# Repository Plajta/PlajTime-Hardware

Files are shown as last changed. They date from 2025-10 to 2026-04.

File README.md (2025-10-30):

# PlajTime Hardware
This repository has the full history of PlajTime hardware development.
Before 19.9.2025 development took place in a single private repository and it was starting to be a little bit messy.
With beginning work on PlajTime's second prototype we made the decision to split the repos and make the code and design finally available.

## What about the older versions?
Every "release" will have it's own tag so you (and we) can look at the older versions and laugh how bad at engineering we are.

## License

This project is licensed under the [Creative Commons Attribution-NonCommercial-ShareAlike 4.0 International License](https://creativecommons.org/licenses/by-nc-sa/4.0/).



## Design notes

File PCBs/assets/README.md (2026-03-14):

# PlajTime PCB Assets
- `source files` - contains sources for further editing - state before converting broken things and fonts to paths
- For some text we used the awesome ISO style font [osifont](https://github.com/hikikomori82/osifont)

## How to align full board SVG graphics
- open the import graphics menu
- disable "Fix discontinuities"
- set scale to 1.0
- `lime.svg`
    - Align RP USB GND pin and Main flash corners with the alignment marks in the SVG
- `aux_*.svg`
    - Align the GND pogo pad on USB and GND pad on slider controller
- `bat_*.svg`
    - Align the two vias to GND and BATT_NTC
- Double click any part of the SVG and click on the alignment marks to delete them
- Profit

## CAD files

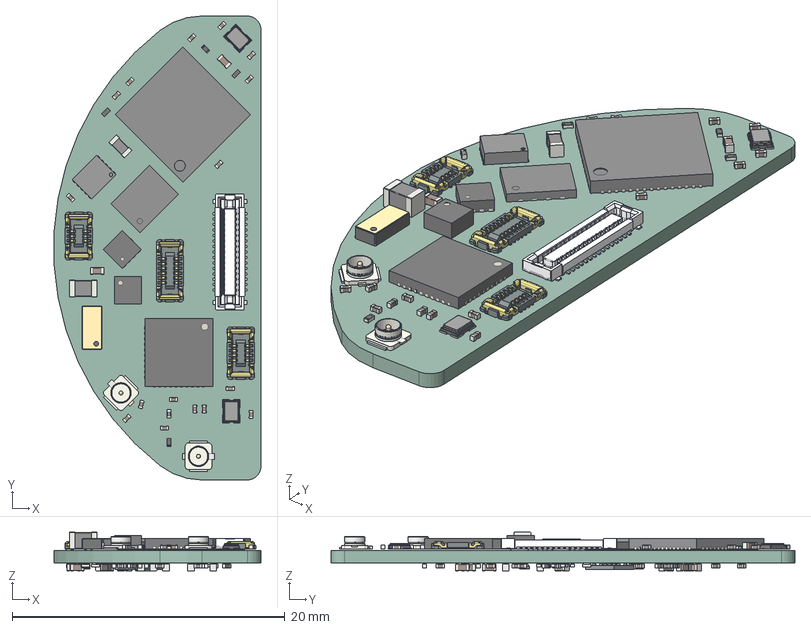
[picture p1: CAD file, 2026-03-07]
PCBs/plajtime-main/plajtime-main.step
15.2 x 34.0 x 2.83 mm
C_0201_0603Metric x 33
R_0201_0603Metric x 12
LGA-12_2x2mm_P0.5mm
L_0603_1608Metric
Texas_RUN0010A_WQFN-10_2x2mm_P0.5mm
Crystal_SMD_WE_IQXC-26-4Pin_1.6x1.2mm x 2
QFN-40-1EP_5x5mm_P0.4mm_EP3.6x3.6mm
U.FL_Hirose_U.FL-R-SMT-1_Vertical x 2
Rect2
Rect3
Rect4
Rect5
Terminal
ThermalPin
PinsArrayLR
W25Q64JWUUIQ_TR
L_0201_0603Metric x 2
L_0805_2012Metric
axe530127
C_0402_1005Metric x 12
RP2350A-QFN60
L_0402_1005Metric
Texas_DSBGA-6_0.757x1.01mm_Layout2x3_P0.35mm
R_0402_1005Metric
W25Q64JWBYIM_TR
plajtime-main_PCB

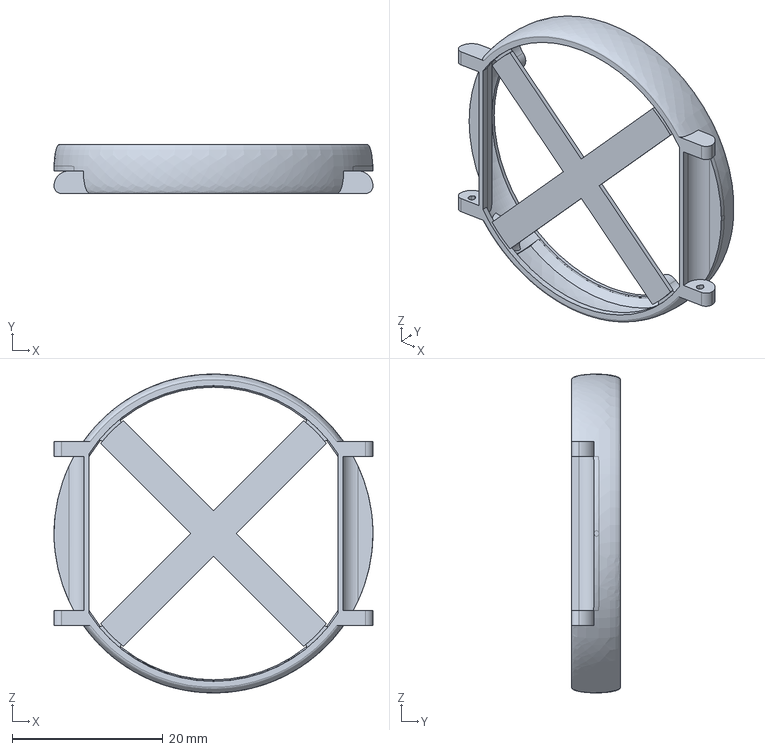
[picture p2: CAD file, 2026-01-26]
3D/STLs/PlajTime-mainFrame.step
42.3 x 6.50 x 42.3 mm

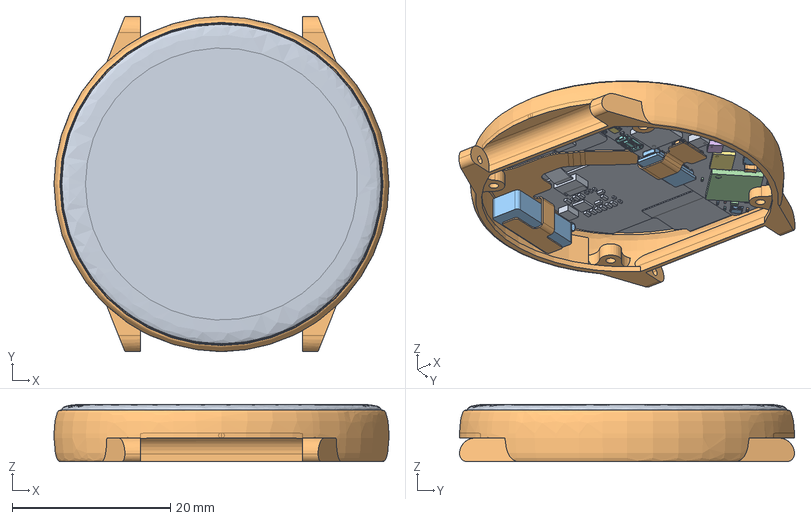
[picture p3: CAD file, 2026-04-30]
3D/PlajTime.FCStd
42.3 x 42.3 x 7.25 mm
display
mainFrame
haptic
C_0201_0603Metric
C_0201_0603Metric001
R_0201_0603Metric
R_0201_0603Metric001
C_0201_0603Metric002
LGA-12_2x2mm_P0.5mm
L_0603_1608Metric
C_0201_0603Metric003
C_0201_0603Metric004
R_0201_0603Metric002
Texas_RUN0010A_WQFN-10_2x2mm_P0.5mm
Crystal_SMD_WE_IQXC-26-4Pin_1.6x1.2mm
C_0201_0603Metric005
QFN-40-1EP_5x5mm_P0.4mm_EP3.6x3.6mm
Crystal_SMD_WE_IQXC-26-4Pin_1.6x1.2mm001
C_0201_0603Metric006
C_0201_0603Metric007
U.FL_Hirose_U.FL-R-SMT-1_Vertical
Rect2
Rect3
Rect4
Rect5
Terminal
Terminal001
Terminal002
Terminal003
C_0201_0603Metric008
ThermalPin
PinsArrayLR
PinsArrayLR001
PinsArrayLR002
PinsArrayLR003
PinsArrayLR004
PinsArrayLR005
PinsArrayLR006
PinsArrayLR007
PinsArrayLR008
PinsArrayLR009
W25Q64JWUUIQ_TR
L_0201_0603Metric
C_0201_0603Metric009
L_0805_2012Metric
axe530127
C_0402_1005Metric
R_0201_0603Metric003
C_0201_0603Metric010
C_0201_0603Metric011
C_0201_0603Metric012
C_0201_0603Metric013
C_0201_0603Metric014
RP2350A-QFN60
U.FL_Hirose_U.FL-R-SMT-1_Vertical001
C_0402_1005Metric001
C_0201_0603Metric015
C_0201_0603Metric016
C_0402_1005Metric002
C_0201_0603Metric017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

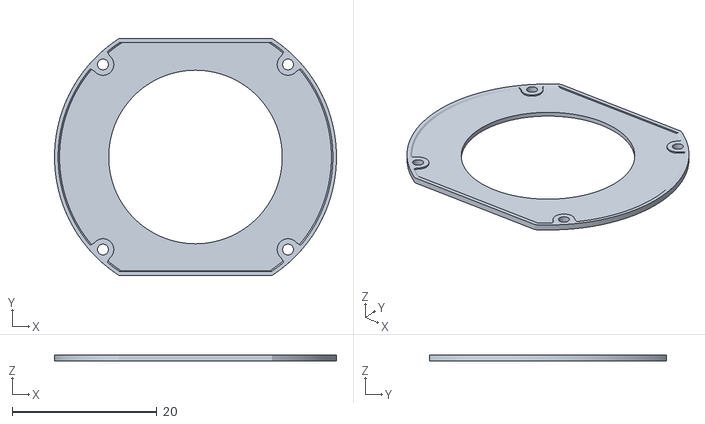
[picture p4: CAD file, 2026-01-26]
3D/STLs/PlajTime-bottom1.stl
39.0 x 32.8 x 0.8

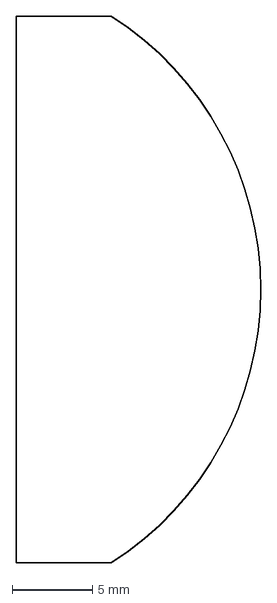
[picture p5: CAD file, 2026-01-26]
PCBs/plajtime-main/3D_Models/PCB_edgecut.dxf
15.2 x 34.0 mm

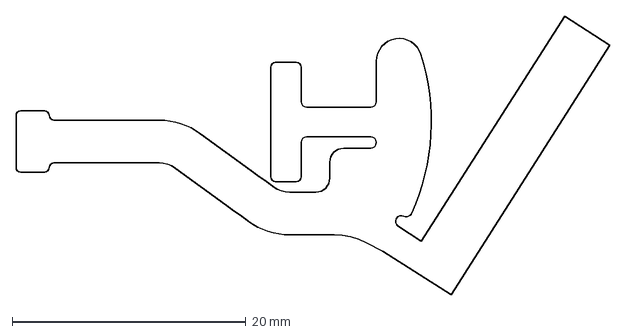
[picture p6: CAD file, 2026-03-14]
3D/PlajTime-AUX_FPCB_Unfold_Outline.dxf
50.8 x 23.8 mm

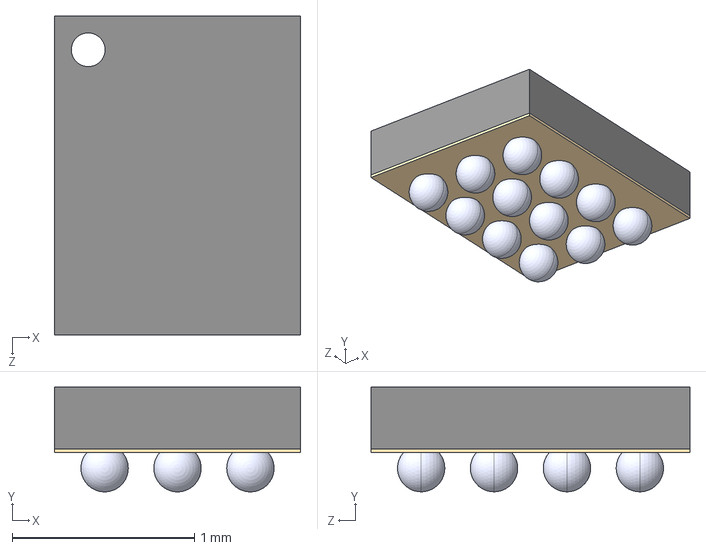
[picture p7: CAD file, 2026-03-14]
PCBs/plajtime-aux/3D_models/DA7280.step
1.35 x 0.575 x 1.75 mm

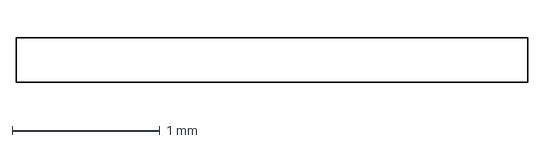
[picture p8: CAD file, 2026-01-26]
PCBs/plajtime-main/3D_Models/DisplayConnectorOffset.dxf
3.47 x 0.3 mm

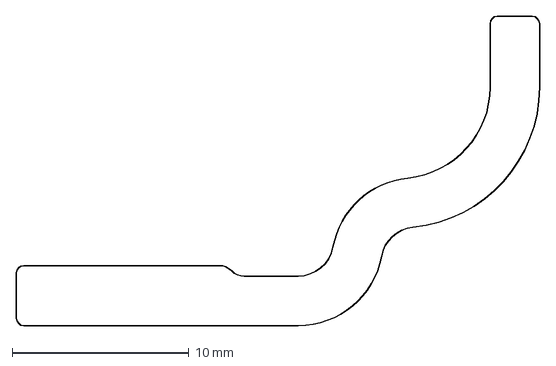
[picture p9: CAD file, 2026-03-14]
3D/PlajTime-Bat_FPCB_Unfold_Outline.dxf
29.6 x 17.5 mm

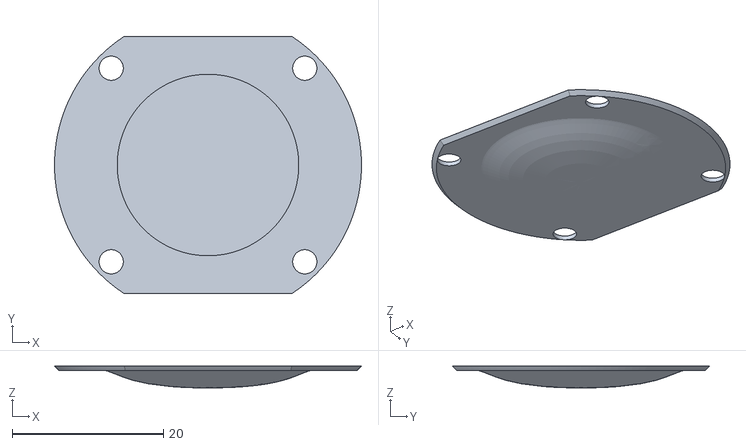
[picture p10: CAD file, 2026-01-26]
3D/STLs/PlajTime-botom2.stl
40.6 x 34.0 x 2.90

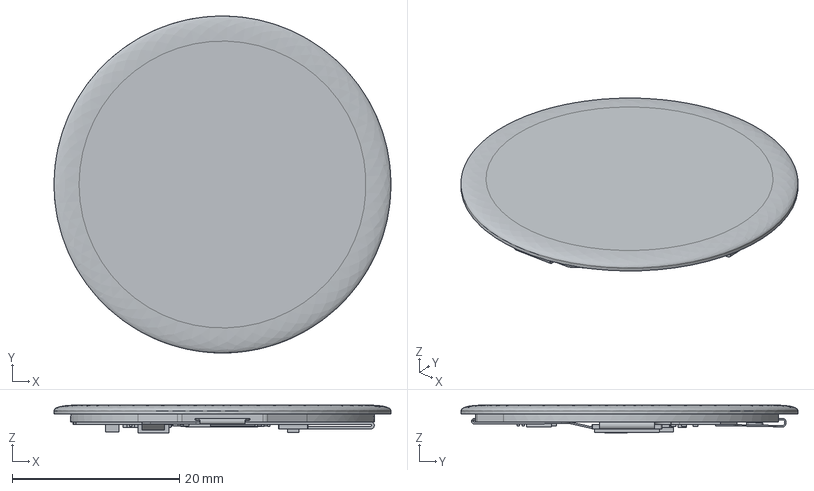
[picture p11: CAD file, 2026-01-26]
PCBs/plajtime-main/3D_Models/display.step
40.4 x 40.4 x 3.34 mm

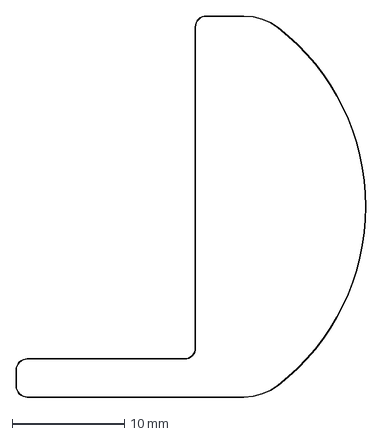
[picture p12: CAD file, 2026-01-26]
3D/pcb_edgecut.dxf
31.2 x 34.0 mm

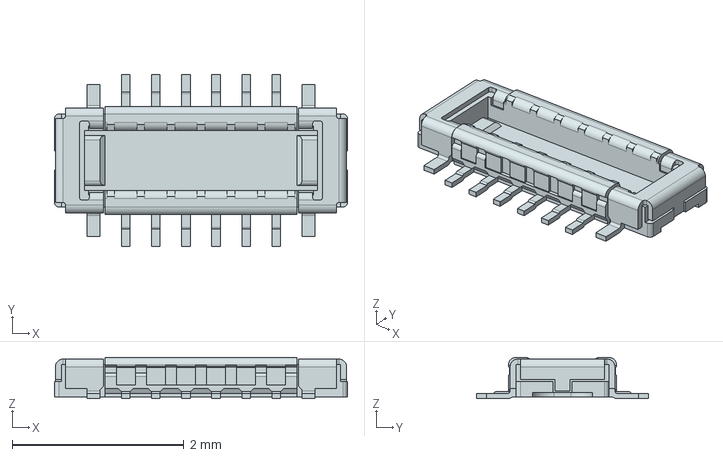
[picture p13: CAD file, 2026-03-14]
PCBs/plajtime-aux/3D_models/5050701222.stp
3.41 x 2.00 x 0.48 mm

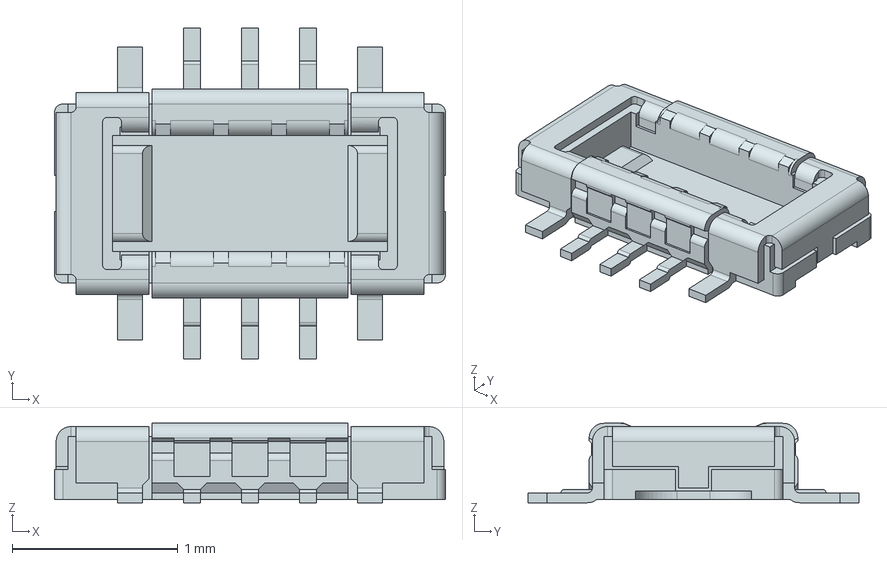
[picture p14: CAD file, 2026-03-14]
PCBs/plajtime-bat-fpcb/3D_models/5050700622.stp
2.36 x 2.00 x 0.48 mm

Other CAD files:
3D/screw_margin.dxf
3D/STLs/PlajTime-mainFrame.3mf
3D/STLs/PlajTime-mainFrame.stl

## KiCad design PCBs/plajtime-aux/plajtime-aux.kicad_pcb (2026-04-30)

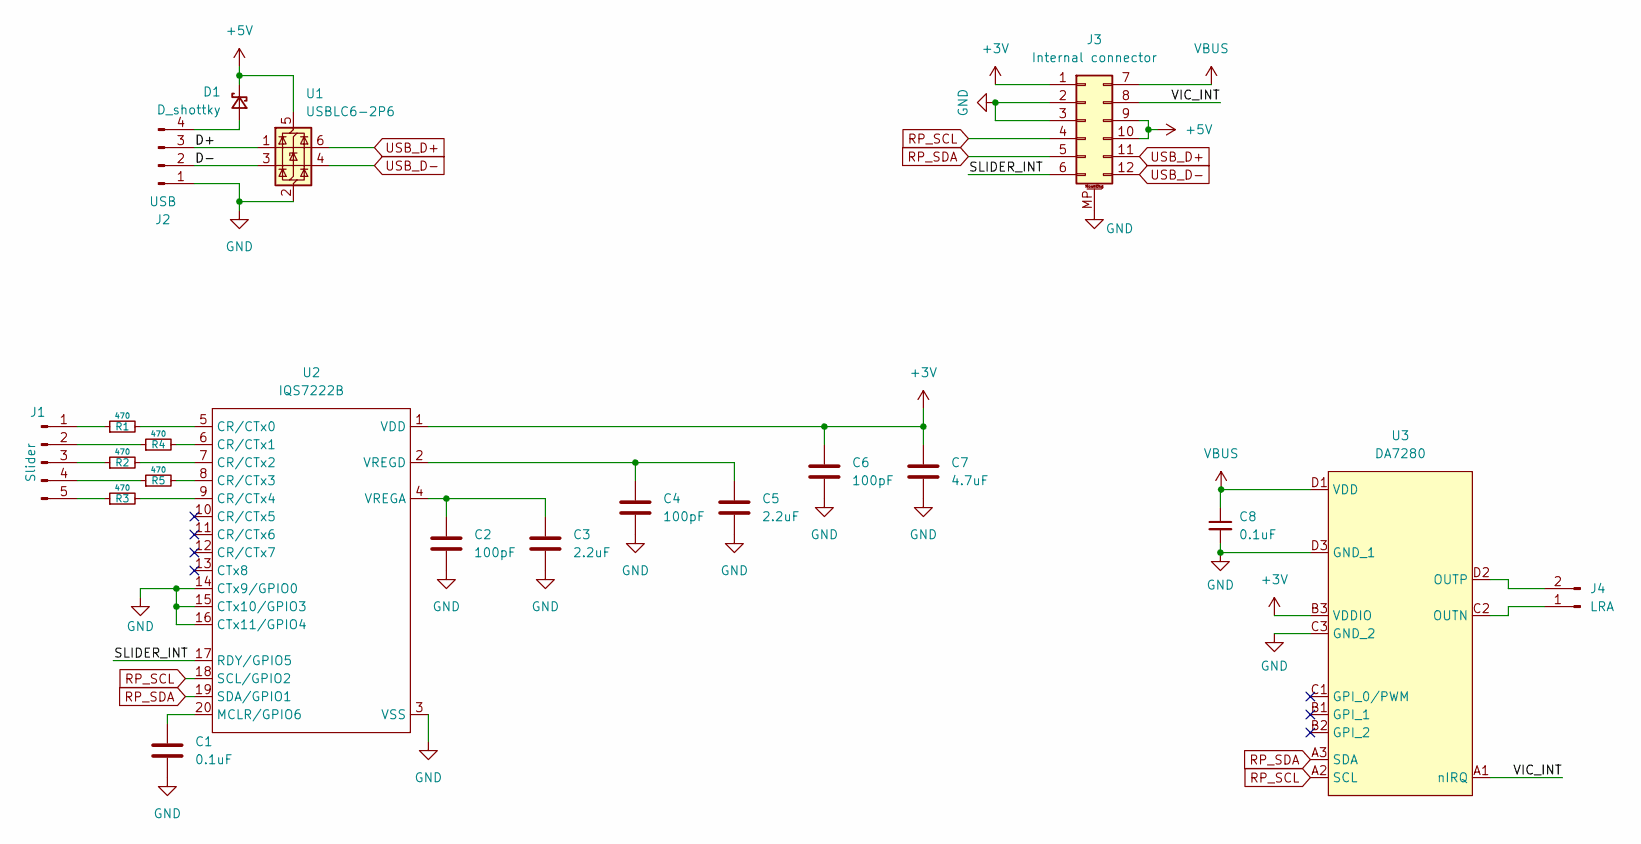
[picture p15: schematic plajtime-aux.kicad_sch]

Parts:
C1, C8: 0.1uF; C_0201_0603Metric; LCSC_Part C161494
C2, C4, C6: 100pF; C_0201_0603Metric; LCSC_Part C541236
C3, C5: 2.2uF; C_0201_0603Metric; Mouser 81-GRM033R61A225KE7D
C7: 4.7uF; C_0402_1005Metric; LCSC_Part C23733
D1: D_shottky; D_0402_1005Metric; LCSC_Part C94366
J1: Slider; TouchSlider-5_25.0248x4.2mm
J2: USB; PinHeader_1x04_P2.54mm_Vertical
J3: Internal connector; 5050701222; Mouser 538-505070-1222
J4: LRA; PinHeader_1x02_P1.00mm_Vertical
R1, R2, R3, R4, R5: 470; R_0201_0603Metric; LCSC_Part C18164334
U1: USBLC6-2P6; PESD3V3L5UF115; LCSC_Part C478118
U2: IQS7222B; QFN-20-1EP_3x3mm_P0.4mm_EP1.65x1.65mm; Mouser 957-IQS7222B102QNR
U3: DA7280; BGA12C40P3X4_135X175X58; Mouser 724-DA7280-00V42

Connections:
+3V: C6.1, C7.1, J3.1, U2.1 (VDD), U3.B3 (VDDIO)
+5V: D1.1 (K), J3.9, J3.10, U1.5 (VBUS)
/D+: J2.3, U1.1 (I/O1)
/D-: J2.2, U1.3 (I/O2)
/SLIDER_INT: J3.6, U2.17 (RDY/GPIO5)
/VIC_INT: J3.8, U3.A1 (nIRQ)
GND: C1.2, C2.2, C3.2, C4.2, C5.2, C6.2, C7.2, C8.2, J2.1, J3.2, J3.3, J3.MP (MountPin), U1.2 (GND), U2.3 (VSS), U2.14 (CTx9/GPIO0), U2.15 (CTx10/GPIO3), U2.16 (CTx11/GPIO4), U2.21 (EP), U3.C3 (GND_2), U3.D3 (GND_1)
unnamed: D1.2 (A), J2.4
unnamed: J1.1, R1.1
unnamed: J1.2, R4.1
unnamed: J1.3, R2.1
unnamed: J1.4, R5.1
unnamed: J1.5, R3.1
unnamed: J4.1, U3.C2 (OUTN)
unnamed: J4.2, U3.D2 (OUTP)
unnamed: R1.2, U2.5 (CR/CTx0)
unnamed: R4.2, U2.6 (CR/CTx1)
unnamed: R2.2, U2.7 (CR/CTx2)
unnamed: R5.2, U2.8 (CR/CTx3)
unnamed: R3.2, U2.9 (CR/CTx4)
unnamed: C1.1, U2.20 (MCLR/GPIO6)
unnamed: C2.1, C3.1, U2.4 (VREGA)
unnamed: C4.1, C5.1, U2.2 (VREGD)
RP_SCL: J3.4, U2.18 (SCL/GPIO2), U3.A2 (SCL)
RP_SDA: J3.5, U2.19 (SDA/GPIO1), U3.A3 (SDA)
USB_D+: J3.11, U1.6 (I/O1)
USB_D-: J3.12, U1.4 (I/O2)
VBUS: C8.1, J3.7, U3.D1 (VDD)

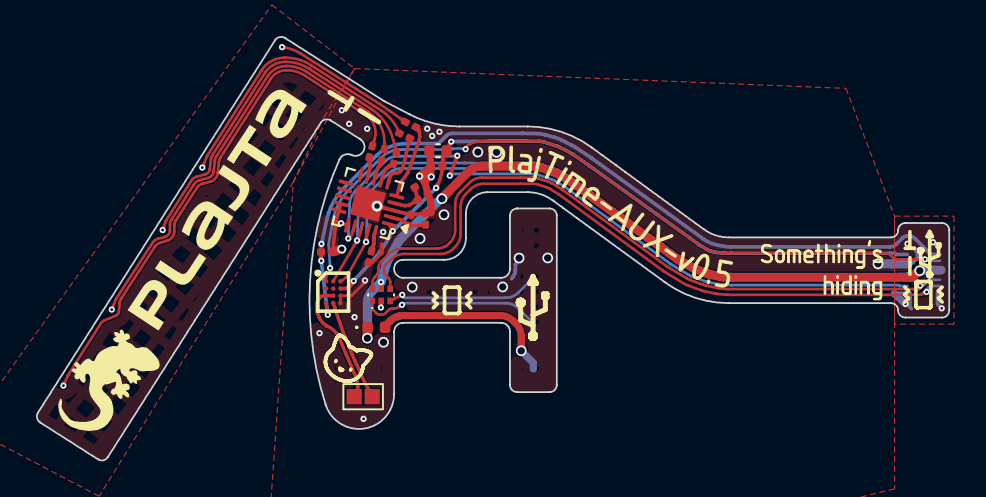
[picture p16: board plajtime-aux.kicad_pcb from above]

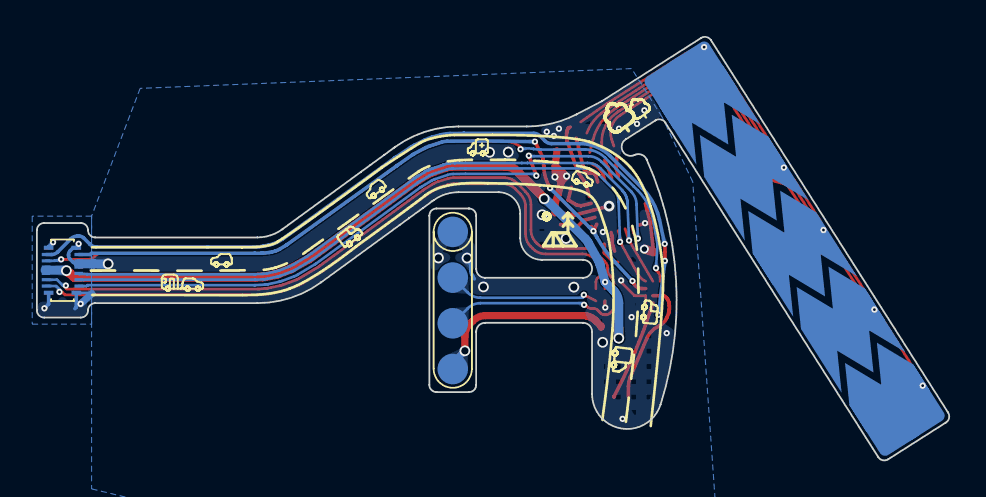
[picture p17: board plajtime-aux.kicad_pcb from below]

Board: 2 copper layers, 50.7 x 23.5 mm, 21 parts (3 on the bottom side), 28 nets.

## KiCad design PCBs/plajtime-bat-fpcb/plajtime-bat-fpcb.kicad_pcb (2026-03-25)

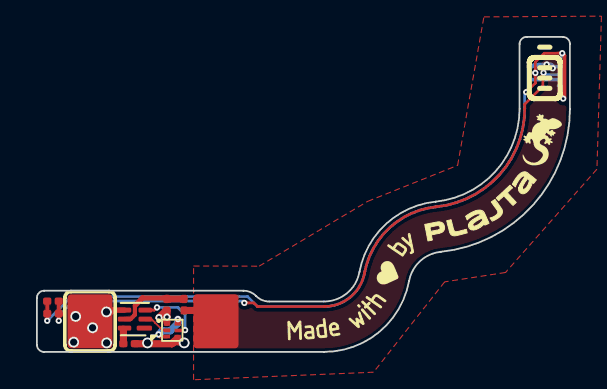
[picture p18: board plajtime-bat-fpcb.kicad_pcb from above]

Board: 2 copper layers, 29.6 x 17.5 mm, 9 parts (1 on the bottom side), 10 nets.

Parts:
BT1: Battery_Cell; Battery
C1: 0.1uF; C_0201_0603Metric
J7: Battery Connector; CONN_505070-0622_MOL
Q1: NX7002BKXBZ; DFN1010B-6
R1: 330; R_0201_0603Metric
R2: 2.2k; R_0201_0603Metric
R3: 26.1k; R_0201_0603Metric
TH1: Thermistor_NTC; R_0201_0603Metric
U1: BQ297xy; WSON-6_1.5x1.5mm_P0.5mm

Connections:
+BATT: BT1.1 (+), J7.1, J7.2, R1.1
-BATT: J7.5, J7.6, Q1.4 (S), R2.2
-CELL: BT1.2 (-), C1.2, Q1.1 (S), U1.4 (VSS)
/BATT_NTC: J7.3, R3.2, TH1.1
GND: J7.4, J7.MP (MountPin), R3.1, TH1.2
unnamed: Q1.3 (D), Q1.6 (D)
unnamed: Q1.2 (G), U1.2 (Cout)
unnamed: Q1.5 (G), U1.3 (Dout)
unnamed: C1.1, R1.2, U1.5 (BAT)
unnamed: R2.1, U1.6 (V-)

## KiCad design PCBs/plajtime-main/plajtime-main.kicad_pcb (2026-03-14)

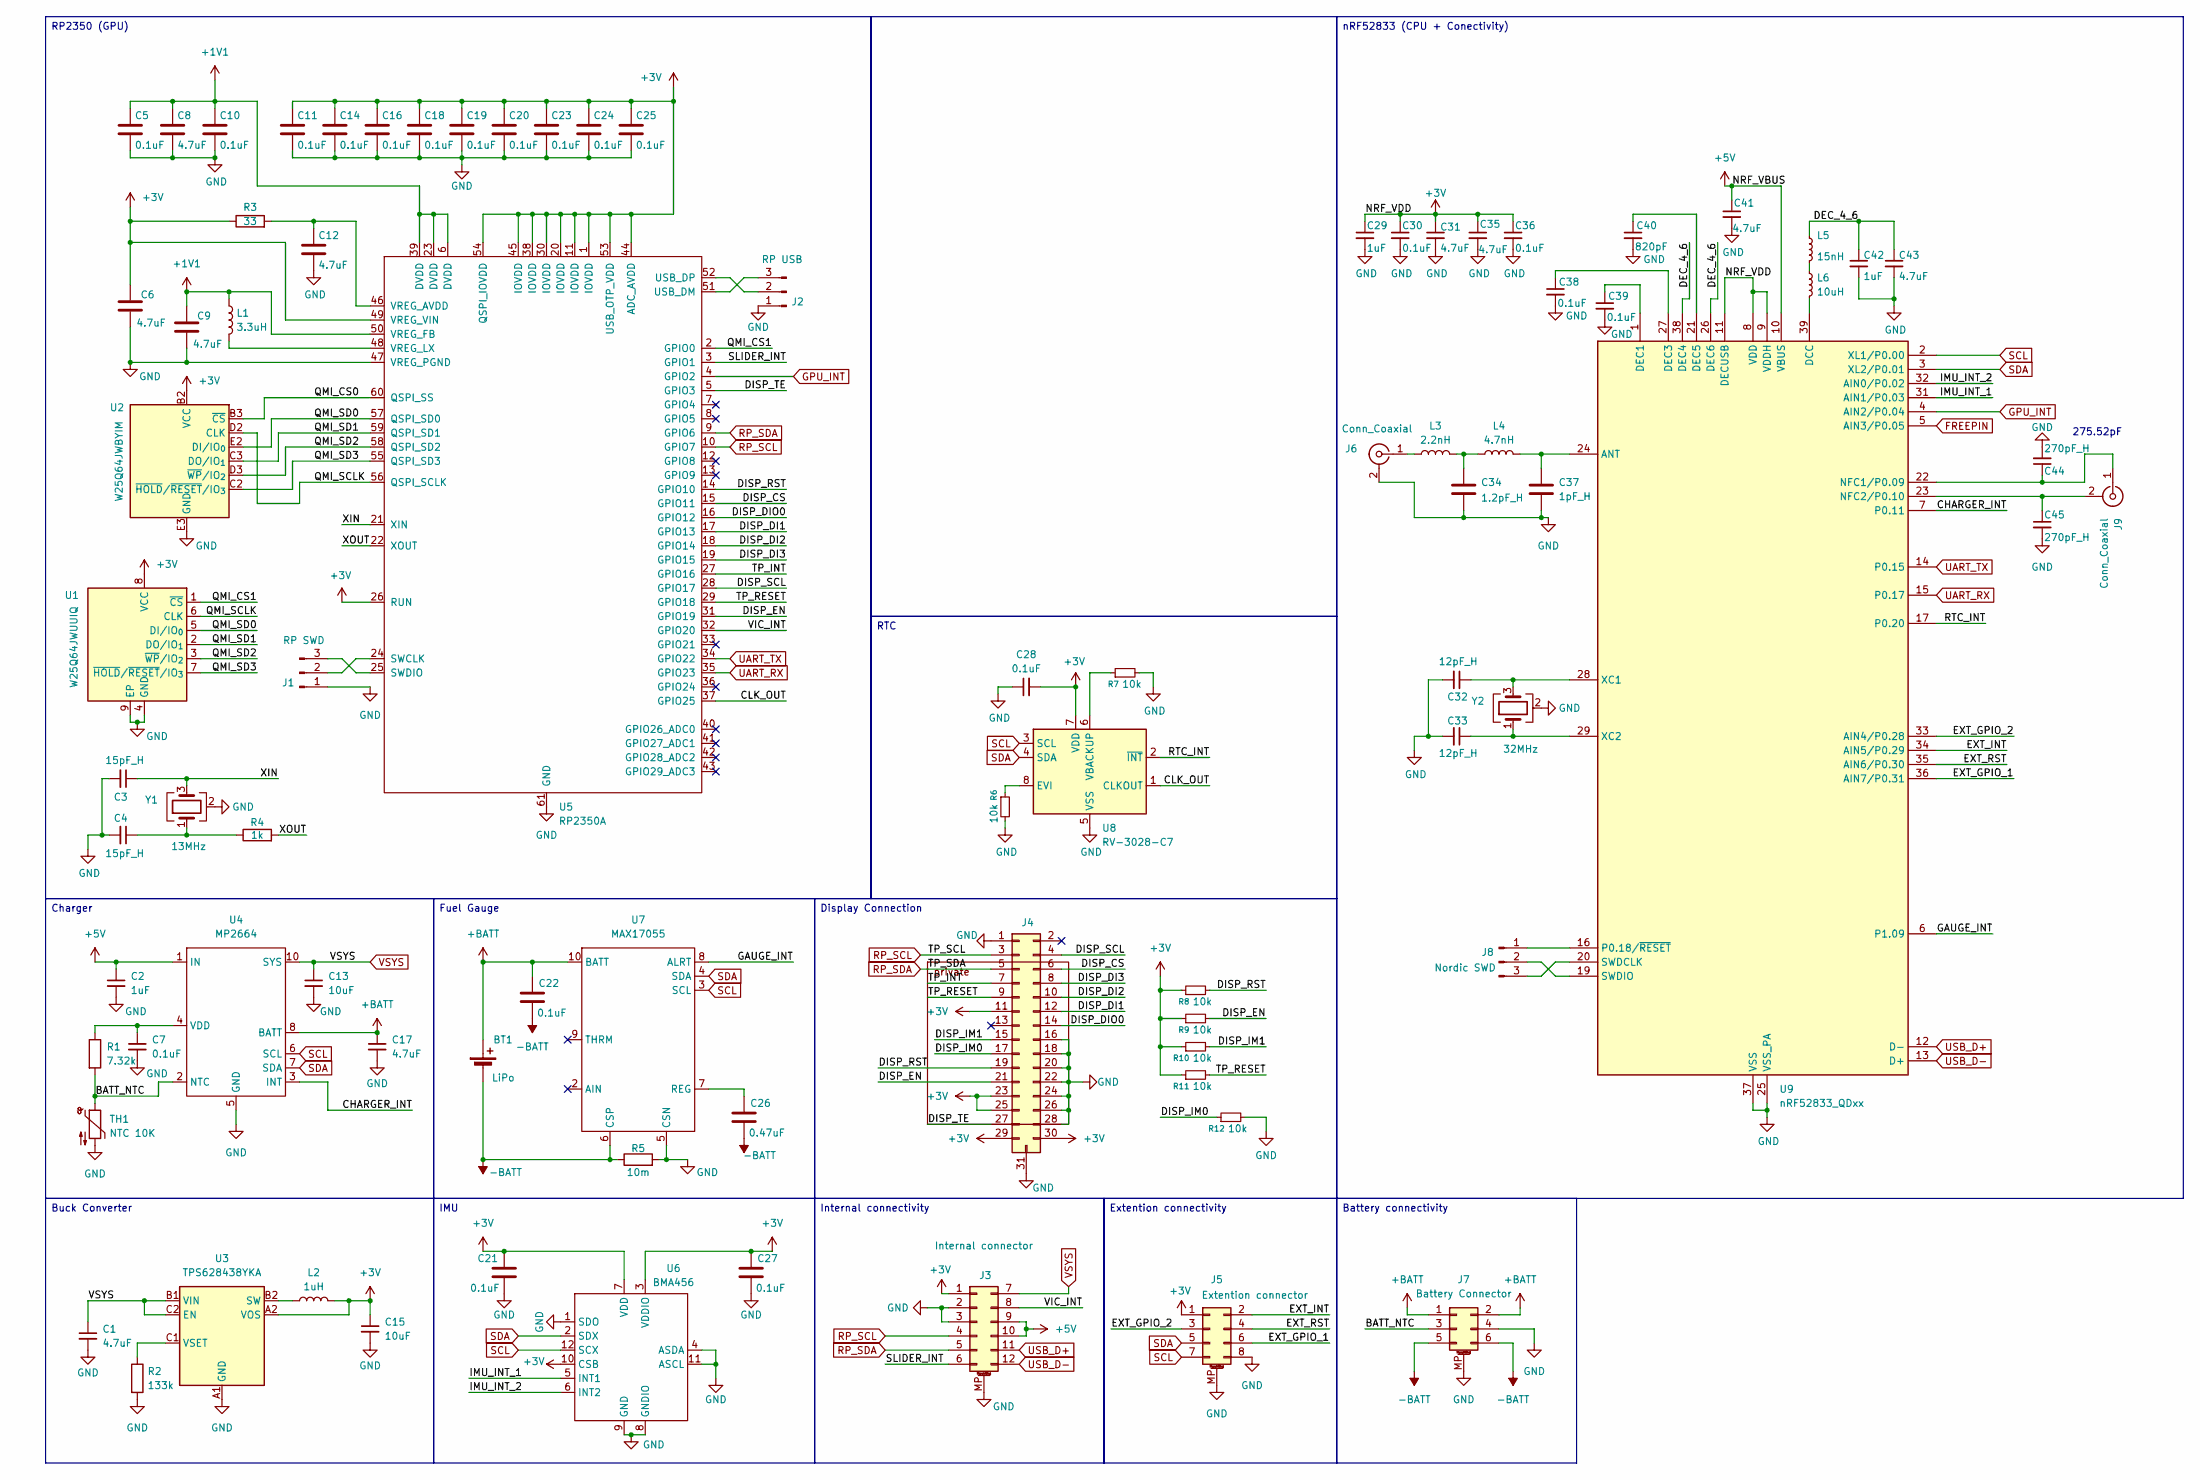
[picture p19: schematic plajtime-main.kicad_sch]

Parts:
BT1: LiPo
C1, C6, C8, C9, C12, C17, C31, C35, C41, C43: 4.7uF; C_0402_1005Metric; LCSC_Part C23733
C2, C29, C42: 1uF; C_0201_0603Metric; LCSC_Part C14445
C3, C4: 15pF_H; C_0201_0603Metric; LCSC_Part C541244
C5, C7, C10, C11, C14, C16, C18, C19, C20, C21, C22, C23, C24, C25, C27, C28, C30, C36, C38, C39: 0.1uF; C_0201_0603Metric; LCSC_Part C161494
C13, C15: 10uF; C_0402_1005Metric; LCSC_Part C315248
C26: 0.47uF; C_0201_0603Metric; LCSC_Part C85926
C32, C33: 12pF_H; C_0201_0603Metric; LCSC_Part C541243
C34: 1.2pF_H; C_0201_0603Metric; LCSC_Part C48642883
C37: 1pF_H; C_0201_0603Metric; LCSC_Part C41361064
C40: 820pF; C_0201_0603Metric; LCSC_Part C5182410
C44, C45: 270pF_H; C_0201_0603Metric; LCSC_Part C430710
J1: RP SWD; PinHeader_1x03_P1.00mm_Vertical
J2: RP USB; PinHeader_1x03_P1.00mm_Vertical
J3: Internal connector; CONN12_505066-1222_179x87_MOL; LCSC_Part C5902841
J4: Display connector; ConnectorDisplay-30; LCSC_Part C425103
J5: Extention connector; 5050660822; LCSC_Part C3652707
J6, J9: Conn_Coaxial; W.FL_Hirose_W.FL2-R-SMT-1_Vertical; LCSC_Part C434809
J7: Battery Connector; CONN_505066-0622_MOL; LCSC_Part C724122
J8: Nordic SWD; PinHeader_1x03_P1.00mm_Vertical_1
L1: 3.3uH; L_0603_1608Metric; LCSC_Part C48945007
L2: 1uH; L_0805_2012Metric; LCSC_Part C223144
L3: 2.2nH; R_0201_0603Metric; LCSC_Part C86107
L4: 4.7nH; L_0201_0603Metric; LCSC_Part C162621
L5: 15nH; L_0201_0603Metric; LCSC_Part C381787
L6: 10uH; L_0402_1005Metric; LCSC_Part C910650
R1: 7.32k; R_0201_0603Metric; LCSC_Part C321025
R2: 133k; R_0201_0603Metric; LCSC_Part C6463015
R3: 33; R_0201_0603Metric; LCSC_Part C295794
R4: 1k; R_0201_0603Metric; LCSC_Part C138165
R5: 10m; R_0402_1005Metric; LCSC_Part C3024467
R6, R7, R8, R9, R10, R11, R12: 10k; R_0201_0603Metric; LCSC_Part C106225
TH1: NTC 10K
U1: W25Q64JWUUIQ; Winbond_USON-8-2EP_3x4mm_P0.8mm_EP0.2x0.8mm; Mouser 454-W25Q64JWUUIQTR
U2: W25Q64JWBYIM; BGA-24_4x6_6.0x6.0mm; LCSC_Part C2691929
U3: TPS628438YKA; Texas_DSBGA-6_0.757x1.01mm_Layout2x3_P0.35mm; LCSC_Part C18197908
U4: MP2664; MPS_MP2664_QFN-10_2x2mm_P0.5mm; Mouser 946-MP2664GG-0000-P
U5: RP2350A; QFN-60-1EP_7x7mm_P0.4mm_EP3.4x3.4mm; Mouser 358-SC150913
U6: BMA456; LGA-12_2x2mm_P0.5mm
U7: MAX17055; SON40P250X200X80-11N; LCSC_Part C2976422
U8: RV-3028-C7; MicroCrystal_C7_SON-8_1.5x3.2mm_P0.9mm; LCSC_Part C3019759
U9: nRF52833_QDxx; QFN-40-1EP_5x5mm_P0.4mm_EP3.6x3.6mm; Mouser 949-NRF52833-QDAA-R
Y1: 13MHz; Oscillator_SMD_Abracon_ASCO-4Pin_1.6x1.2mm; LCSC_Part C20625731
Y2: 32MHz; Crystal_SMD_WE_IQXC-26-4Pin_1.6x1.2mm; LCSC_Part C7301921

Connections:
+1V1: C5.1, C8.1, C9.1, C10.1, L1.1, U5.6 (DVDD), U5.23 (DVDD), U5.39 (DVDD), U5.50 (VREG_FB)
+3V: C6.1, C11.1, C14.1, C15.1, C16.1, C18.1, C19.1, C20.1, C21.1, C23.1, C24.1, C25.1, C27.1, C28.2, C29.1, C30.1, C31.1, C35.1, C36.1, J3.1, J4.11, J4.23, J4.25, J4.29, J4.30, J5.1, L2.2, R3.1, R8.1, R9.1, R10.1, R11.1, U1.8 (VCC), U2.B2 (VCC), U3.A2 (VOS), U5.1 (IOVDD), U5.11 (IOVDD), U5.20 (IOVDD), U5.26 (RUN), U5.30 (IOVDD), U5.38 (IOVDD), U5.44 (ADC_AVDD), U5.45 (IOVDD), U5.49 (VREG_VIN), U5.53 (USB_OTP_VDD), U5.54 (QSPI_IOVDD), U6.3 (VDDIO), U6.7 (VDD), U6.10 (CSB), U8.7 (VDD), U9.8 (VDD), U9.9 (VDDH), U9.11 (DECUSB), U9.18 (VDD), U9.30 (VDD), U9.40 (VDD)
+5V: C2.1, C41.1, J3.9, J3.10, U4.1 (IN), U9.10 (VBUS)
+BATT: BT1.1 (+), C17.1, C22.1, J7.1, J7.2, U4.8 (BATT), U4.9 (BATT), U7.10 (BATT)
-BATT: BT1.2 (-), C22.2, C26.2, J7.5, J7.6, R5.1, U7.6 (CSP), U7.11 (CSP)
/BATT_NTC: J7.3, R1.2, TH1.1, U4.2 (NTC)
/CHARGER_INT: U4.3 (INT), U9.7 (P0.11)
/CLK_OUT: U5.37 (GPIO25), U8.1 (CLKOUT)
/DEC_4_6: C42.1, C43.1, L5.1, U9.26 (DEC6), U9.38 (DEC4)
/DISP_CS: J4.6, U5.15 (GPIO11)
/DISP_DI1: J4.12, U5.17 (GPIO13)
/DISP_DI2: J4.10, U5.18 (GPIO14)
/DISP_DI3: J4.8, U5.19 (GPIO15)
/DISP_DIO0: J4.14, U5.16 (GPIO12)
/DISP_EN: J4.21, R9.2, U5.31 (GPIO19)
/DISP_IM0: J4.17, R12.1
/DISP_IM1: J4.15, R10.2
/DISP_RST: J4.19, R8.2, U5.14 (GPIO10)
/DISP_SCL: J4.4, U5.28 (GPIO17)
/DISP_TE: J4.27, U5.5 (GPIO3)
/EXT_GPIO_1: J5.6, U9.36 (AIN7/P0.31)
/EXT_GPIO_2: J5.3, U9.33 (AIN4/P0.28)
/EXT_INT: J5.2, U9.34 (AIN5/P0.29)
/EXT_RST: J5.4, U9.35 (AIN6/P0.30)
/GAUGE_INT: U7.8 (ALRT), U9.6 (P1.09)
/IMU_INT_1: U6.5 (INT1), U9.31 (AIN1/P0.03)
/IMU_INT_2: U6.6 (INT2), U9.32 (AIN0/P0.02)
/QMI_CS0: U2.B3 (~CS), U5.60 (QSPI_SS)
/QMI_CS1: U1.1 (~CS), U5.2 (GPIO0)
/QMI_SCLK: U1.6 (CLK), U2.D2 (CLK), U5.56 (QSPI_SCLK)
/QMI_SD0: U1.5 (DI/IO_{0}), U2.E2 (DI/IO_{0}), U5.57 (QSPI_SD0)
/QMI_SD1: U1.2 (DO/IO_{1}), U2.C3 (DO/IO_{1}), U5.59 (QSPI_SD1)
/QMI_SD2: U1.3 (~WP/IO_{2}), U2.D3 (~WP/IO_{2}), U5.58 (QSPI_SD2)
/QMI_SD3: U1.7 (~HOLD/~RESET/IO_{3}), U2.C2 (~HOLD/~RESET/IO_{3}), U5.55 (QSPI_SD3)
/RTC_INT: U8.2 (~INT), U9.17 (P0.20)
/SLIDER_INT: J3.6, U5.3 (GPIO1)
/TP_INT: J4.7, U5.27 (GPIO16)
/TP_RESET: J4.9, R11.2, U5.29 (GPIO18)
/VIC_INT: J3.8, U5.32 (GPIO20)
/XIN: C3.1, U5.21 (XIN), Y1.3
/XOUT: R4.2, U5.22 (XOUT)
FREEPIN: U9.5 (AIN3/P0.05)
GND: C1.2, C2.2, C3.2, C4.2, C5.2, C6.2, C7.2, C8.2, C9.2, C10.2, C11.2, C12.2, C13.2, C14.2, C15.2, C16.2, C17.2, C18.2, C19.2, C20.2, C21.2, C23.2, C24.2, C25.2, C27.2, C28.1, C29.2, C30.2, C31.2, C32.2, C33.2, C34.2, C35.2, C36.2, C37.2, C38.2, C39.2, C40.2, C41.2, C42.2, C43.2, C44.2, C45.2, J1.1, J2.1, J3.2, J3.3, J3.MP (MountPin), J4.1, J4.16, J4.18, J4.20, J4.22, J4.24, J4.26, J4.28, J4.31 (MP), J5.8, J5.MP (MountPin), J6.2 (Ext), J7.4, J7.MP (MountPin), R2.2, R5.2, R6.2, R7.2, R12.2, TH1.2, U1.4 (GND), U1.9 (EP), U2.E3 (GND), U3.A1 (GND), U4.5 (GND), U5.47 (VREG_PGND), U5.61 (GND), U6.1 (SDO), U6.4 (ASDA), U6.8 (GNDIO), U6.9 (GND), U6.11 (ASCL), U7.5 (CSN), U8.5 (VSS), U9.25 (VSS_PA), U9.37 (VSS), U9.41 (VSS), Y1.2 (G), Y1.4 (G), Y2.2 (G), Y2.4 (G)
GPU_INT: U5.4 (GPIO2), U9.4 (AIN2/P0.04)
unnamed: C4.1, R4.1, Y1.1
unnamed: C26.1, U7.7 (REG)
unnamed: C34.1, L3.2, L4.1
unnamed: J1.2, U5.24 (SWCLK)
unnamed: J1.3, U5.25 (SWDIO)
unnamed: J2.2, U5.52 (USB_DP)
unnamed: J2.3, U5.51 (USB_DM)
unnamed: J6.1 (In), L3.1
unnamed: J8.1, U9.16 (P0.18/~RESET)
unnamed: J8.2, U9.19 (SWDIO)
unnamed: J8.3, U9.20 (SWDCLK)
unnamed: C45.1, J9.2 (Ext), U9.23 (NFC2/P0.10)
unnamed: C44.1, J9.1 (In), U9.22 (NFC1/P0.09)
unnamed: L5.2, L6.1
unnamed: L2.1, U3.B2 (SW)
unnamed: R2.1, U3.C1 (VSET)
unnamed: C7.1, R1.1, U4.4 (VDD)
unnamed: C12.1, R3.2, U5.46 (VREG_AVDD)
unnamed: L1.2, U5.48 (VREG_LX)
unnamed: R6.1, U8.8 (EVI)
unnamed: R7.1, U8.6 (VBACKUP)
unnamed: C37.1, L4.2, U9.24 (ANT)
unnamed: L6.2, U9.39 (DCC)
unnamed: C39.1, U9.1 (DEC1)
unnamed: C38.1, U9.27 (DEC3)
unnamed: C40.1, U9.21 (DEC5)
unnamed: C32.1, U9.28 (XC1), Y2.3
unnamed: C33.1, U9.29 (XC2), Y2.1
RP_SCL: J3.4, J4.3, U5.10 (GPIO7)
RP_SDA: J3.5, J4.5, U5.9 (GPIO6)
SCL: J5.7, U4.6 (SCL), U6.12 (SCX), U7.3 (SCL), U8.3 (SCL), U9.2 (XL1/P0.00)
SDA: J5.5, U4.7 (SDA), U6.2 (SDX), U7.4 (SDA), U8.4 (SDA), U9.3 (XL2/P0.01)
UART_RX: U5.35 (GPIO23), U9.15 (P0.17)
UART_TX: U5.34 (GPIO22), U9.14 (P0.15)
USB_D+: J3.11, U9.12 (D-)
USB_D-: J3.12, U9.13 (D+)
VSYS: C1.1, C13.1, J3.7, U3.B1 (VIN), U3.C2 (EN), U4.10 (SYS)

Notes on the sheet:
275.52pF
Extention connectivity
Charger
Display Connection
Buck Converter
Internal connectivity
IMU
Battery connectivity
RP2350 (GPU)
RTC
nRF52833 (CPU + Conectivity)
Fuel Gauge

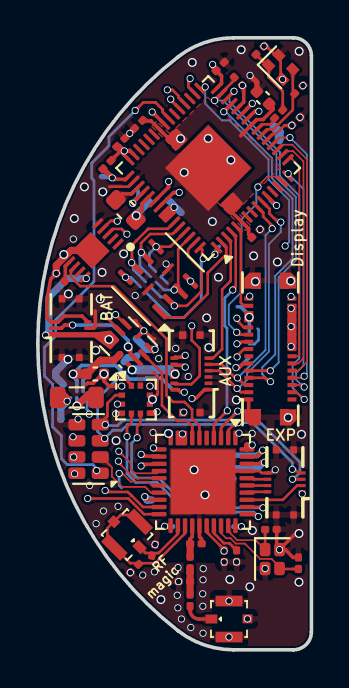
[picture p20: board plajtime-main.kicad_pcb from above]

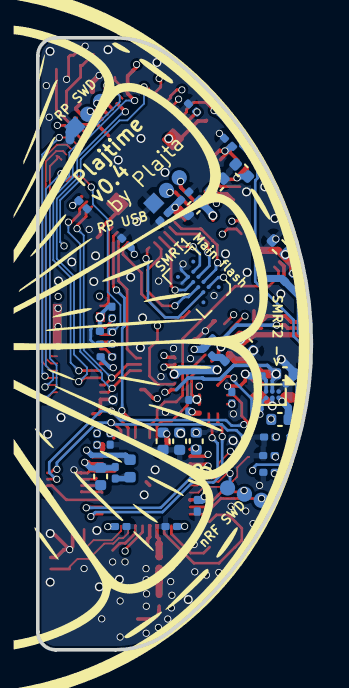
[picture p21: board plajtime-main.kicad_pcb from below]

Board: 6 copper layers, 15.2 x 34.0 mm, 83 parts (43 on the bottom side), 80 nets.

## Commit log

2025-10-30 Squished prototype v0.3 archive
    [2328702-4.stp, 505110-0592.stp, 6pin_conn.stp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]
2025-10-30 Clean repo for next prototype
    [2328702-4.stp, 505110-0592.stp, 6pin_conn.stp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]
2025-10-30 3D: Add model to show required fitting space
    [PlajTime.FCStd]
2026-01-26 3D is now has its sizes, PCB has almost done schematic and started work on layout
    [DisplayConnectorOffset.dxf, PCB_edgecut.dxf, PlajTime-botom2.stl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]
2026-02-06 Some layout is done
    [PlajTime.FCStd, plajtime-main.kicad_pcb, plajtime-main.kicad_sch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]
2026-02-09 Some small changes
    [plajtime-main.kicad_pcb]
2026-02-09 Add and modify labels
    Modify mainly text thickness
    [plajtime-main.kicad_pcb]
2026-02-09 Move text around a bit
    for future fruity changes
    [plajtime-main.kicad_pcb]
2026-02-09 Add a nice PCB graphic, tweak text
    Add a nice citrus inspired PCB graphic for the bottom side of PlajTime v0.4
    [plajtime-main.kicad_pcb]
2026-02-09 Some small final touches
    [plajtime-main.kicad_pcb, plajtime-main.kicad_sch]
2026-02-17 Final Main PCB version
    [plajtime-aux.kicad_pcb, plajtime-aux.kicad_sch, plajtime-main.kicad_pcb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]
2026-03-01 Fixes for bug that I found for now, added right models
    [plajtime-main.kicad_pcb]
2026-03-07 feat: Add new KiCad project for battery flexible PCB, updating main, auxiliary, and 3D models.
    [PlajTime.FCStd, plajtime-aux.kicad_sch, plajtime-bat-fpcb.kicad_pcb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]
2026-03-10 Almost done AUX Board
    [plajtime-aux.kicad_pcb, plajtime-aux.kicad_sch]
2026-03-11 Done with battery FPCB
    [plajtime-bat-fpcb.kicad_pcb, plajtime-bat-fpcb.kicad_sch]
2026-03-11 Add graphics for AUX FPCB
    Redo asset README a bit and move assets
    Remove the pogo pins from the solderpaste layer
    [plajtime-aux.kicad_pcb]
2026-03-11 Fix dielectric materials on BAT and AUX
    Add dimensions to BAT and fix it's thickness
    [plajtime-aux.kicad_pcb, plajtime-bat-fpcb.kicad_pcb]
2026-03-11 Update AUX board's top graphic
    [plajtime-aux.kicad_pcb]
2026-03-14 Added stiffener for BAT FPCB
    [plajtime-bat-fpcb.kicad_pcb]
2026-03-14 Done with AUX board
    [plajtime-aux.kicad_pcb, plajtime-aux.kicad_sch]
2026-03-14 Add graphics for BAT FPCB
    Preapplied to the KiCAD files
    [plajtime-bat-fpcb.kicad_pcb]
2026-03-14 Revise and update FPCB graphics
    [plajtime-aux.kicad_pcb]
2026-03-14 Add 3D models for all chips on AUX board
    [DA7280.step, plajtime-aux.kicad_pcb]
2026-03-14 Changes in 3D model
    [PlajTime-AUX_FPCB_Unfold_Outline.dxf, PlajTime-Bat_FPCB_Unfold_Outline.dxf, PlajTime.FCStd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]
2026-03-14 Add 3D models for AUX board and connectors
    [5050700622.stp, 5050701222.stp, plajtime-aux.kicad_pcb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]
2026-03-15 Fix graphics on both FPCBs
    Change how text is put on paths
    Remove country of origin text
    [plajtime-aux.kicad_pcb, plajtime-bat-fpcb.kicad_pcb]
2026-03-15 Update export paths and fills on FPCBs
    [plajtime-aux.kicad_pcb, plajtime-bat-fpcb.kicad_pcb]
2026-03-16 Changed to bigger vias
    [plajtime-bat-fpcb.kicad_pcb]
2026-03-17 Edited via sizes
    [plajtime-aux.kicad_pcb]
2026-03-25 All production fixes
    [plajtime-aux.kicad_pcb, plajtime-bat-fpcb.kicad_pcb]
2026-04-30 Formal remarks, added usb pins holder to model
    [PlajTime.FCStd, plajtime-aux.kicad_pcb, plajtime-main.kicad_sch]
2026-10-10 3d-chassis: Improved USB pogo mount
    The previous version had a very unstable way of mounting the USB pogo
    contacts, which caused the pogos to press against the AMOLED display
    and could eventually break it.
    The new design solves this problem by adding an extra pogo pin to take
    the pressure. They are secured in the bottom cap so they won't push
    into the display. The second change is moving the LRA. Because of the
    additional row of pogos, it can no longer fit under the USB pads, so
    it was moved nearby and now has a more secure mount.
2026-10-10 main-pcb: Project migrated to KiCad 10.0.5
2026-10-10 main-pcb: Fix charger's power off mode, remove RTC
2026-10-10 main-pcb: Add 32.768kHz crystal, Split AUX and USB, retrace changes
2026-10-10 main-pcb: Some fixes after v0.4
2026-10-10 main-pcb: Fix Nordic USB (DECUSB), Improve I2C and RTC crystal routing
    Also added labels for some nets, done basic board cleanup
2026-10-12 main-pcb: Fix charger shutdown properly
    The previous fix used VDD (internal charger voltage), which was
    not allowed. This fix uses the battery directly instead, to create
    a pull-up on the INT pin. Additionally, a resistor is needed between
    the sensing pin and the charger INT pin, because the nRF was pulling
    it too hard, exceeding the minimum pin threshold. Therefore,
    the resistor values should be calculated with this in mind.
